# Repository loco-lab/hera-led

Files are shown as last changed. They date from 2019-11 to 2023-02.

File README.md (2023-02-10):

# hera-led
Contains all the relevant parts to create your own live HERA LED display.  
  
HERAlive.py is the main code. It shows the live status of HERA according to the dashboard.  
HERAtest.py is a playground with many different displays to use. Comment and uncomment lines under main() to change what displays.  
  
On the LoCo lab board, HERAlive is setup to run via systemd so that it automatically begins at startup.  
If it is not running, use the following sequence of commands to restart it.
  
sudo systemctl stop HERAlive  
sudo systemctl daemon-reload  
sudo systemctl start HERAlive

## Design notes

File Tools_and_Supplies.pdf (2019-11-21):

Tools and Supplies
While not listed in the bill of materials, these items are necessary for putting the display together. You may have many of them on hand already. The only thing I didn’t have in the lab already was the laser cutter, where I went to a local hobbyist group.
- Hot glue gun with plenty of glue
The LEDs and dishes are glued into place on the middle layer. Hot glue worked great for me, but you’re welcome to try other kinds of glue as well.
- Philips screwdriver
All screws I used are Philips head. Also useful for the LED power supply ports!
- Vice-grip
Good for tightening the screws. My middle board bent which made stacking the 3 boards together difficult without this.
- Scissors
For cutting the labels after printing.
- X-acto knife
Had its many uses, such as removing bad glue applications and cutting the foamcore.
- GPIO female to male jumper cables
You’ll need signal and ground cables running from the Pi to the LEDs. These specific jumper cables slip on to the GPIO pins smoothly and then insert into the LEDs plug.
- Wire cutters and strippers
You’ll need to make some custom wires that are long enough to power the LEDs towards the top of the display. I’ll describe this more in the build guide.
- Double-sided tape
For sticking the labels on the foamcore and the foamcore on the acrylic.
- Electrical tape
I had 2 jumper cables connected end to end for both signal and ground. I used electrical tape to reinforce the joint between them.
- Duct tape
You’ll have 30 extra LEDs hanging out at the end of your string, unused. I taped these to the back side of the display so that they weren’t piled up on the ground.
- Soldering station, solder, heatshrink
Again, you’ll need to make some custom wires.
- 3D printer
All the dishes are 3D printed. We used a Makerbot Replicator+.
- Laser cutter
The 3 main boards are all laser cut for precision. You need a very large laser cutter, at least 30” by 35” (the size of the hex). I used a 31” by 48”.

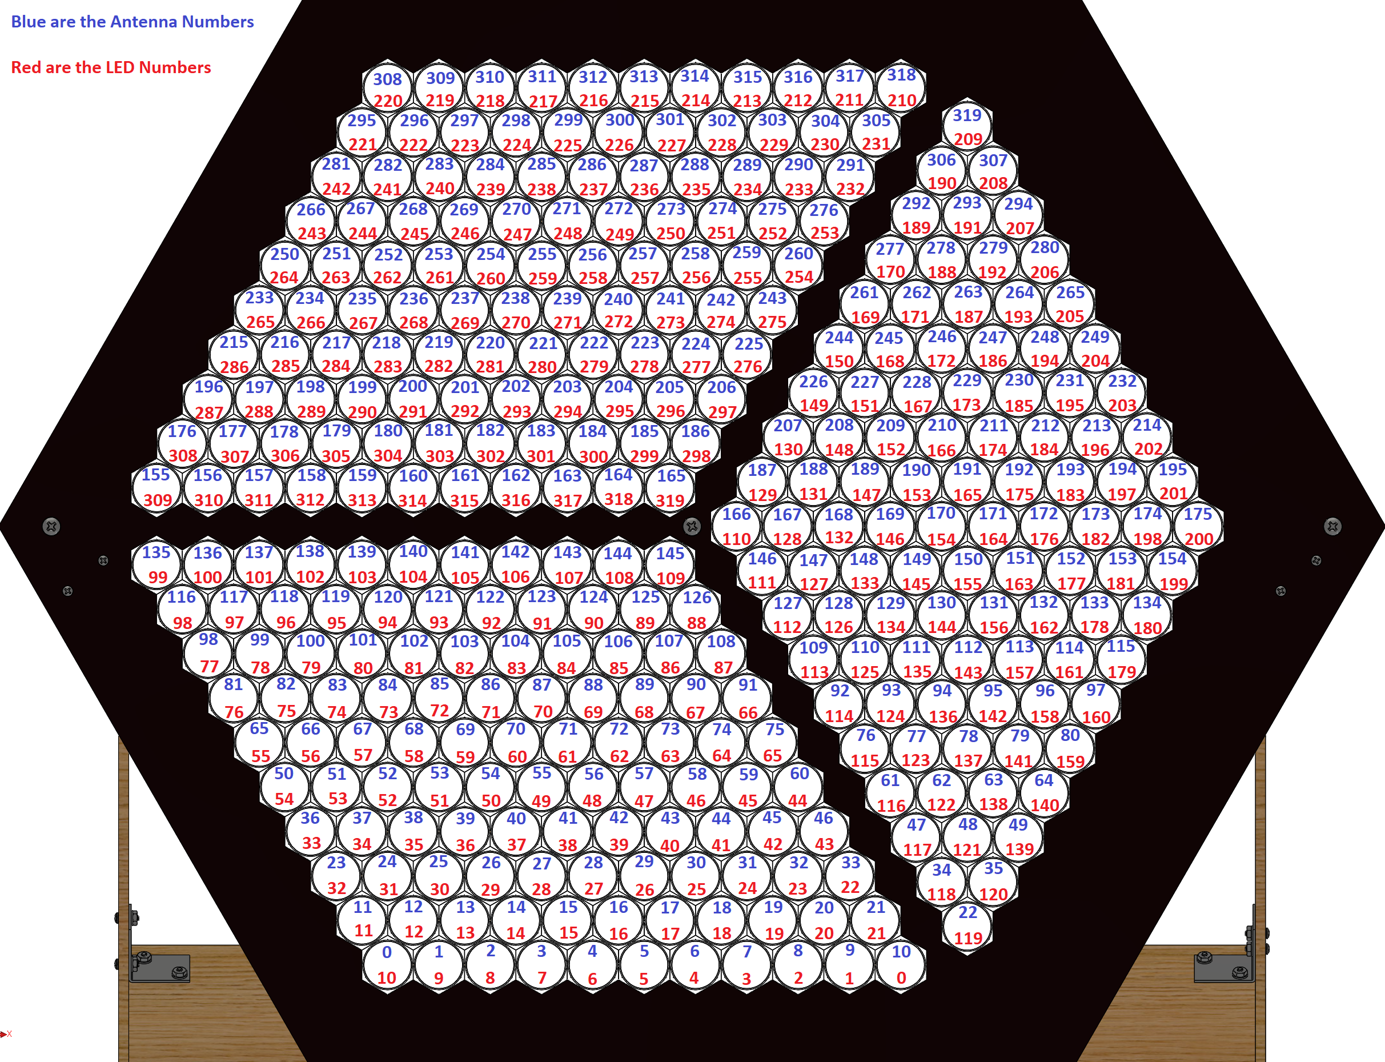
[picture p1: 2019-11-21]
Numbering_Scheme.png

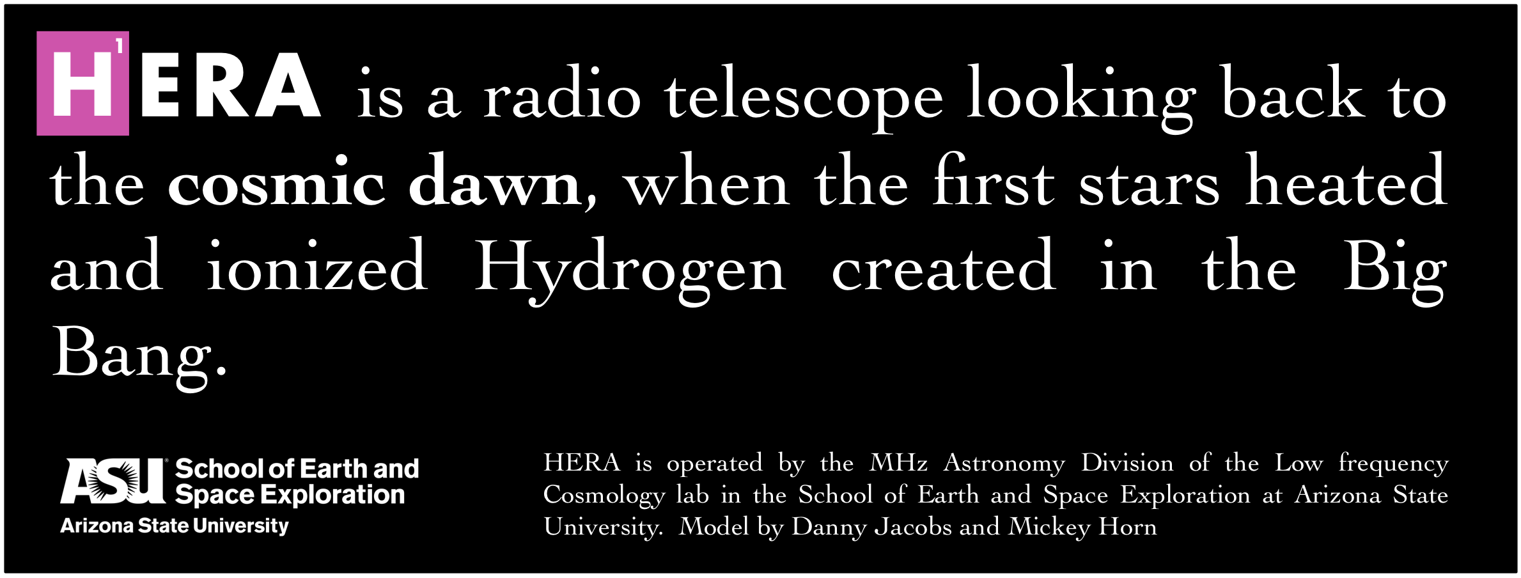
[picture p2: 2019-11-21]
Labels/Label_1.png

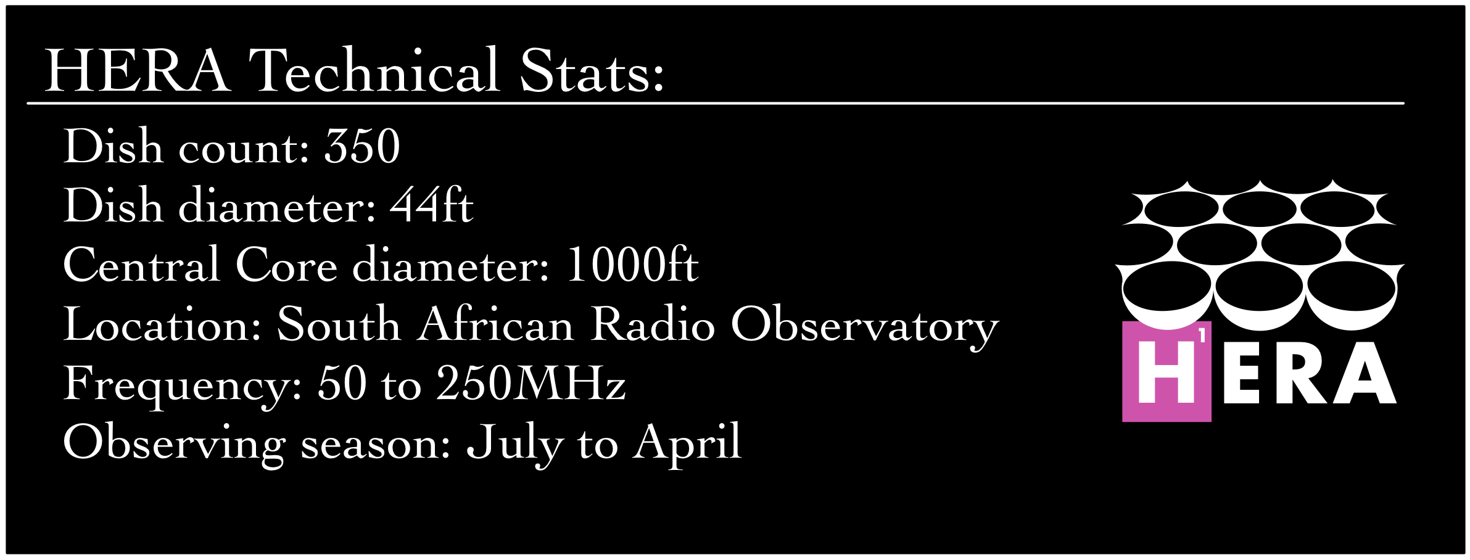
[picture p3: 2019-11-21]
Labels/Label_3.png

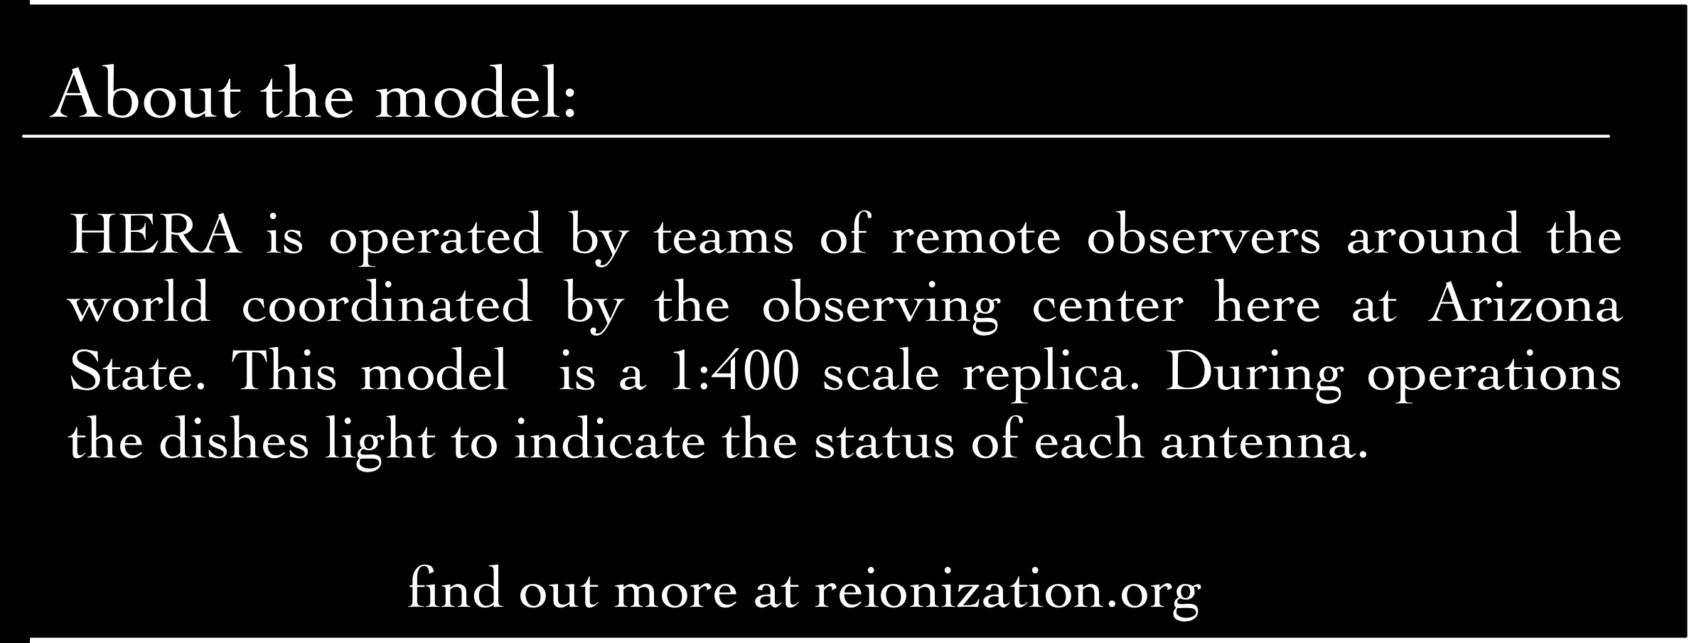
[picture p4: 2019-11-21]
Labels/Label_2.png

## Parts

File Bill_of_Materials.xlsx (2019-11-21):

Item | Specs | Quantity Needed | Quantity per Pack | Packs Needed | Price per Pack | Total Price | Link
Addressable LED Strings | --- | 320 | 500 | 1 | $118.00 | $118.00 | https://www.amazon.com/ALITOVE-LED-Individually-Addressable-Waterproof/dp/B01NCAG8KV
LED Power Supply | --- | 1 | 1 | 1 | $23.99 | $23.99 | https://www.amazon.com/dp/B06XK3X3PW/ref=cm_sw_r_cp_ep_dp_v01ZzbYYBK4NR
LED Power Supply Cable | --- | 1 | 1 | 1 | $7.99 | $7.99 | https://www.amazon.com/dp/B07CWS4BGC
Opaque Black Acrylic | 31" x 31" x 3/16" | 1 | 1 | 1 | $136.35 | $136.35 | https://www.tapplastics.com/product/plastics/cut_to_size_plastic/acrylic_sheets_color/341
Bending Plywood Board | 48" x 48" x 1/8" | 1 | 1 | 1 | $31.99 | $31.99 | https://www.homedepot.com/p/Columbia-Forest-Products-1-8-in-x-4-ft-x-4-ft-PureBond-Radius-Bending-Plywood-Project-Panel-4162/310331847
Red Oak Plywood Board | 48" x 48" x 1/4" | 1 | 1 | 1 | $41.54 | $41.54 | https://www.homedepot.com/p/Columbia-Forest-Products-1-4-in-x-4-ft-x-4-ft-PureBond-Red-Oak-Plywood-Project-Panel-Free-Custom-Cut-Available-2564/204637001
Steel Corner Bracket | 1.5" x 1.5" x 1.25" | 4 | 1 | 4 | $1.64 | $6.56 | https://www.mcmaster.com/17715a75
Titanium Pan Head Screw | M6 x 20mm | 7 | 5 | 2 | $8.75 | $17.50 | https://www.mcmaster.com/90234a367
Titanium Pan Head Screw | 6-32 x 0.5" | 12 | 1 | 12 | $5.20 | $62.40 | https://www.mcmaster.com/90234a210
Titanium Pan Head Screw | 6-32 x 0.75" | 4 | 1 | 4 | $5.93 | $23.72 | https://www.mcmaster.com/90234A215
Black Stainless Steel Washer | M6 | 7 | 100 | 1 | $9.15 | $9.15 | https://www.mcmaster.com/98269a450
Black Stainless Steel Washer | No. 6 | 16 | 100 | 1 | $3.88 | $3.88 | https://www.mcmaster.com/96765a115
Titanium Hex Nut | M6 | 7 | 1 | 7 | $4.58 | $32.06 | https://www.mcmaster.com/91927a115
Titanium Hex Nut | 6-32 | 16 | 1 | 16 | $4.48 | $71.68 | https://www.mcmaster.com/90545a007
Raspberry Pi Model 3 B+ | --- | 1 | 1 | 1 | $35.00 | $35.00 | https://www.canakit.com/raspberry-pi-3-model-b-plus.html
Raspberry Pi Case | --- | 1 | 1 | 1 | $7.95 | $7.95 | https://www.pishop.us/product/designspark-raspberry-pi-3-enclosure-black/
Pi Power Supply | --- | 1 | 1 | 1 | $8.95 | $8.95 | https://www.pishop.us/product/wall-adapter-power-supply-micro-usb-2-4a-5-25v/
Wireless Keyboard+Mouse | --- | 1 | 1 | 1 | $19.95 | $19.95 | https://www.pishop.us/product/full-size-wireless-keyboard-with-trackpad/
HDMI Cable | --- | 1 | 1 | 1 | $2.45 | $2.45 | https://www.pishop.us/product/hdmi-cable-flat-1m/
Wifi Adapter | --- | 1 | 1 | 1 | $8.95 | $8.95 | https://www.pishop.us/product/wireless-n-300mbps-usb-wifi-adapter-hx9500/
MicroSD Card | --- | 1 | 1 | 1 | $14.95 | $14.95 | https://www.pishop.us/product/microsd-card-32-gb-class-10-blank/
Clear Filament | 1.75mm | 3 | 1 | 3 | $42.00 | $126.00 | https://www.matterhackers.com/store/l/clear-translucent-pro-series-pla-filament-1.75mm/sk/MESZ27MX
Black Foamcore Board | --- | 1 | 1 | 1 | $10.00 | $10.00 | https://www.michaels.com/elmers-black-foam-boards-11x14/10308905.html
 |  |  |  |  | Final Price | $821.01

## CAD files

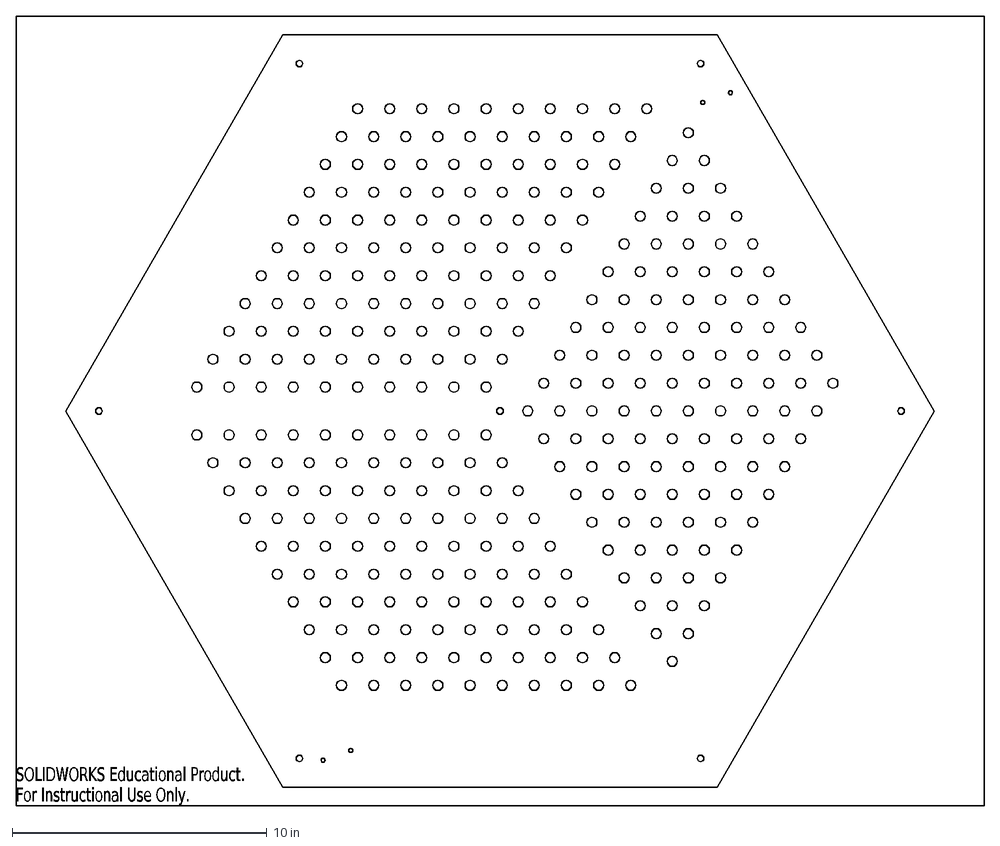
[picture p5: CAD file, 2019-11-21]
Laser_Drawings/Full_Middle_Layer_Drawing.DXF
SOLIDWORKS Educational Product.
For Instructional Use Only.

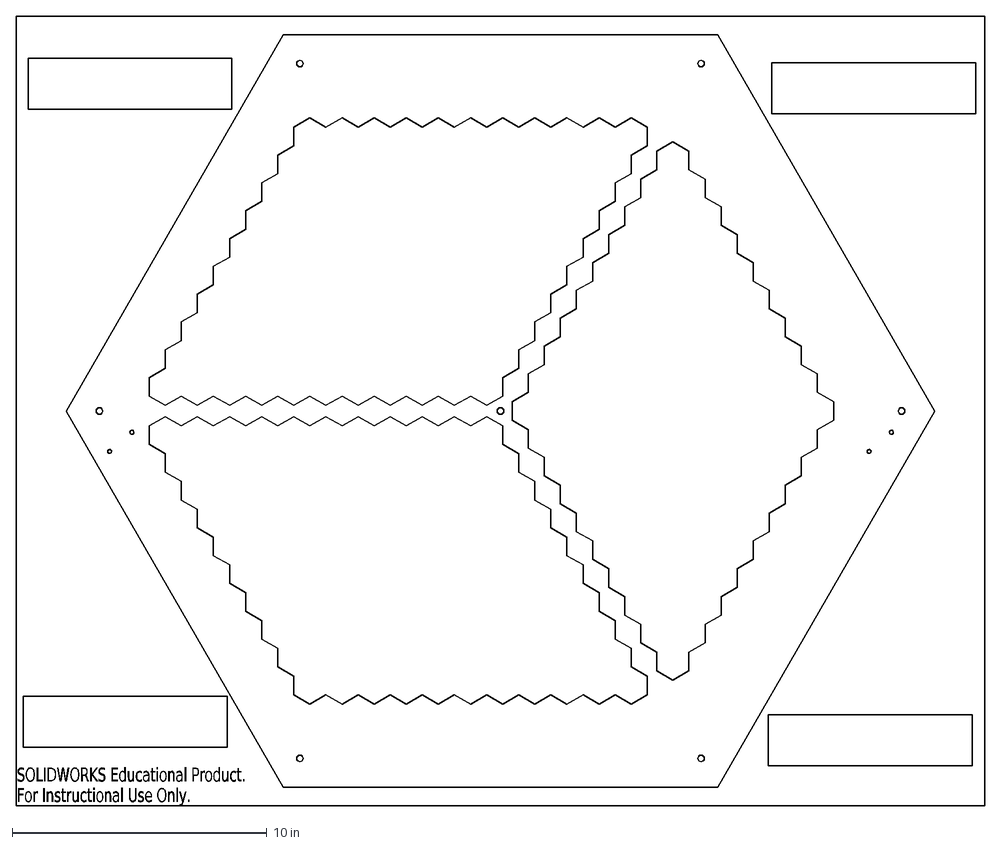
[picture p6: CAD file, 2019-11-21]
Laser_Drawings/Full_Top_Layer_Drawing.DXF
SOLIDWORKS Educational Product.
For Instructional Use Only.

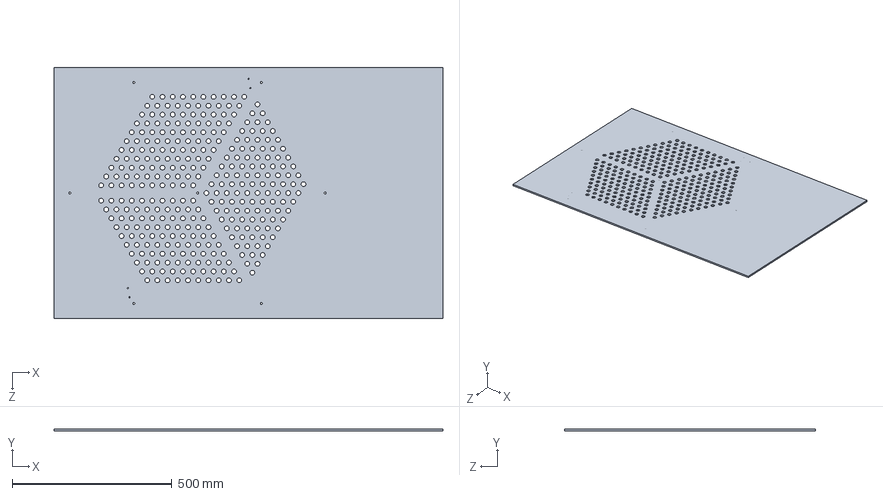
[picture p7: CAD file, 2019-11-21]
Solidworks_Assembly/Full Bottom Layer.SLDPRT
1219.2 x 6.35 x 787.4 mm

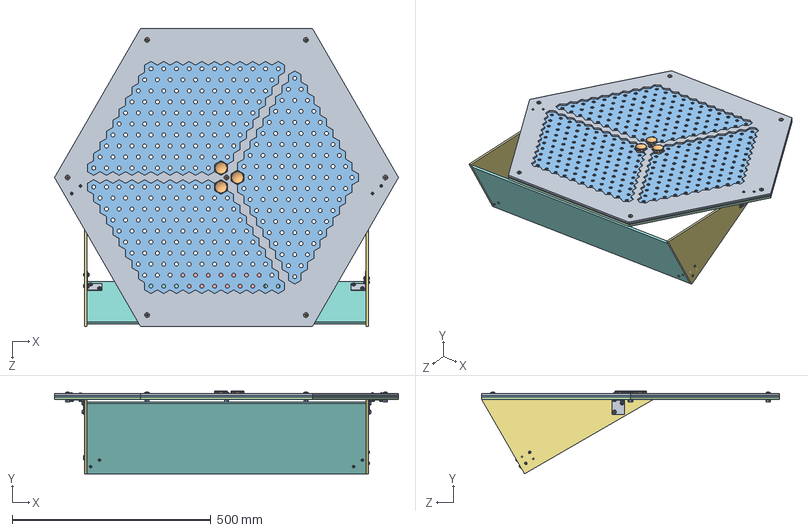
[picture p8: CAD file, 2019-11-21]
Solidworks_Assembly/HERA LED Model Assembly.SLDASM
866.0 x 208.1 x 750.0 mm
Top Layer
Scaled HERA dish LED x 3
Middle Layer
Bottom Layer
Power Supply
Pi 2011.12
Triangle Support x 2
Bottom Plank
Angle Bracket x 4
M6 x 20mm Screw x 7
M6 Nut x 7
M6 Washer x 7
6-32 x 0.75in Screw x 4
6-32 Nut x 16
6-32 Washer x 16
6-32 x 0.5in Screw x 12

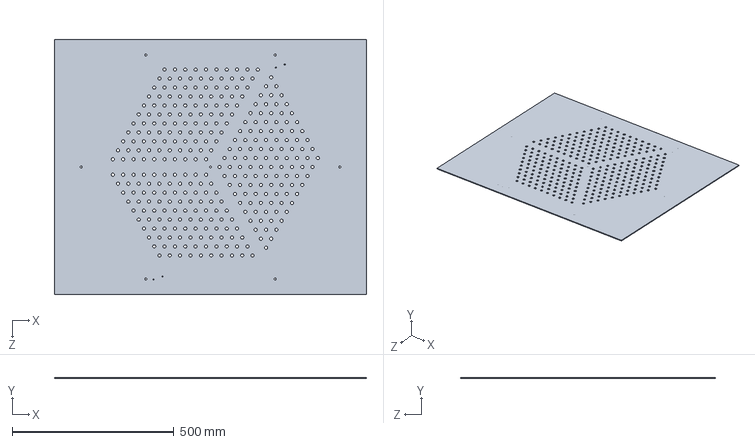
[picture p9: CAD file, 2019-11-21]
Solidworks_Assembly/Full Middle Layer.SLDPRT
965.2 x 3.17 x 787.4 mm

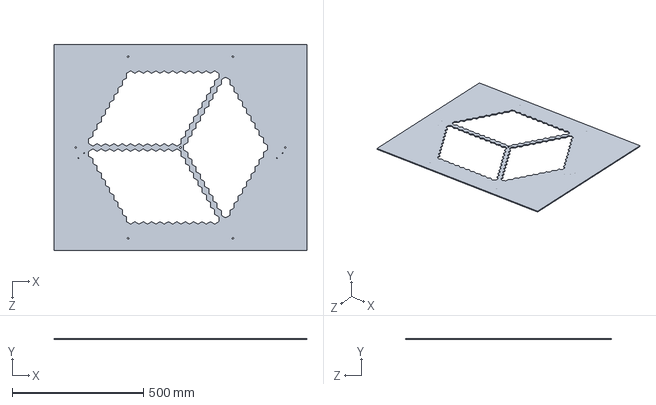
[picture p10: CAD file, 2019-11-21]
Solidworks_Assembly/Full Top Layer.SLDPRT
965.2 x 4.76 x 787.4 mm

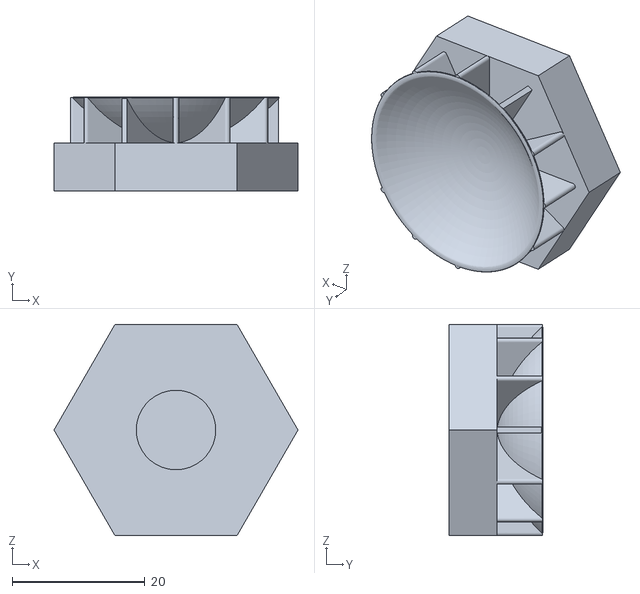
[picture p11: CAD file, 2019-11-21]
Scaled_HERA_Dish_LED_forprint.STL
36.8 x 14.2 x 31.9

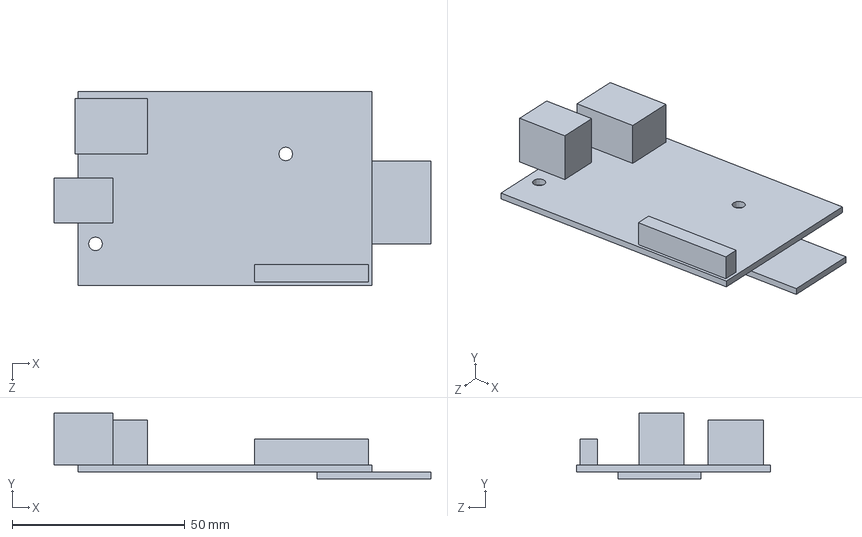
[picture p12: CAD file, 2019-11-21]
Solidworks_Assembly/Pi 2011.12.SLDPRT
109.0 x 19.0 x 56.0 mm

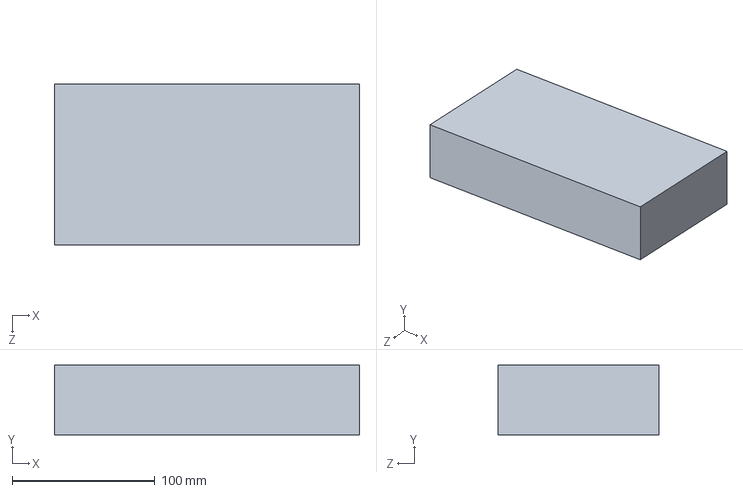
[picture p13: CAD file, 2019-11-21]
Solidworks_Assembly/Power Supply.SLDPRT
214.0 x 49.0 x 113.0 mm

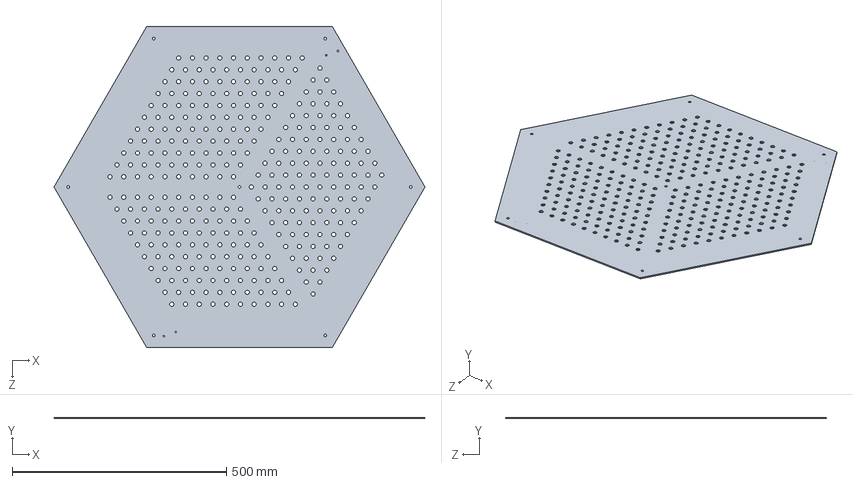
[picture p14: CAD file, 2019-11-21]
Solidworks_Assembly/Middle Layer.SLDPRT
866.0 x 3.17 x 750.0 mm

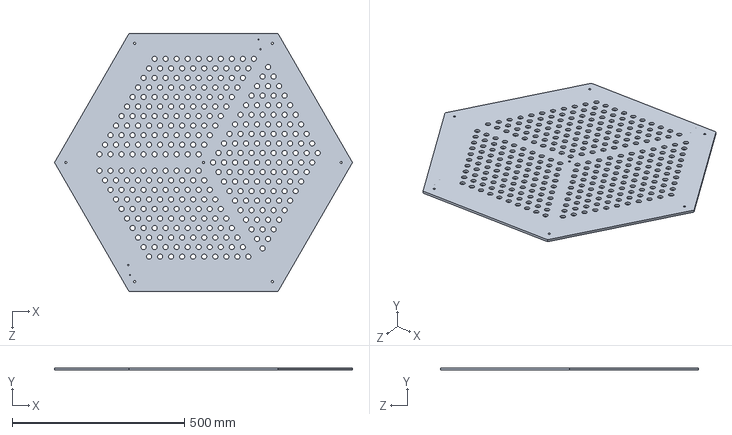
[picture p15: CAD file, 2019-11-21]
Solidworks_Assembly/Bottom Layer.SLDPRT
866.0 x 6.35 x 750.0 mm

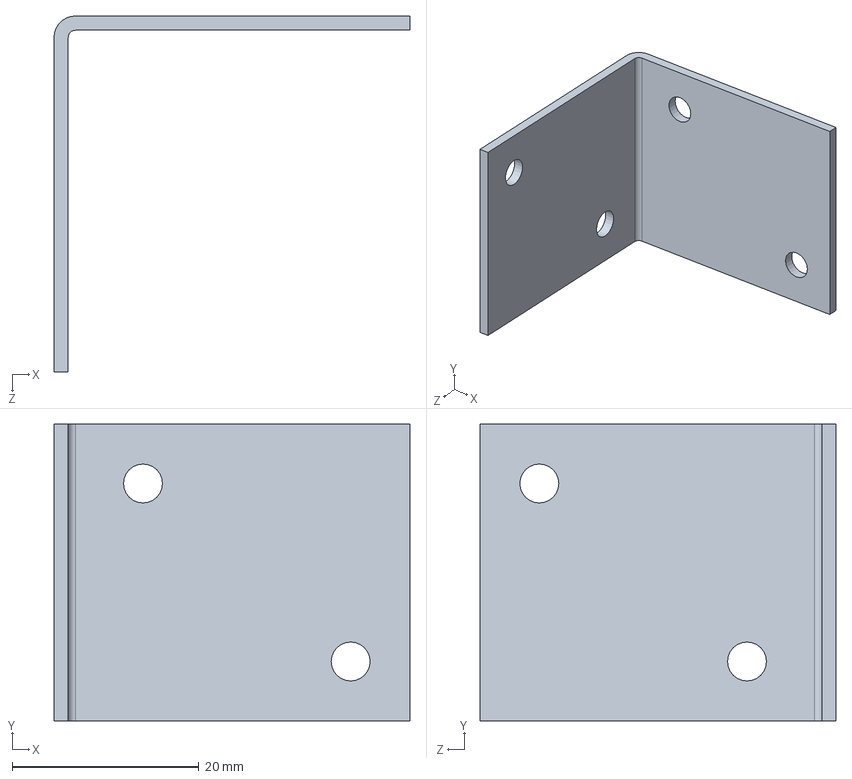
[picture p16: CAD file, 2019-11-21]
Solidworks_Assembly/Angle Bracket.SLDPRT
38.1 x 31.8 x 38.1 mm

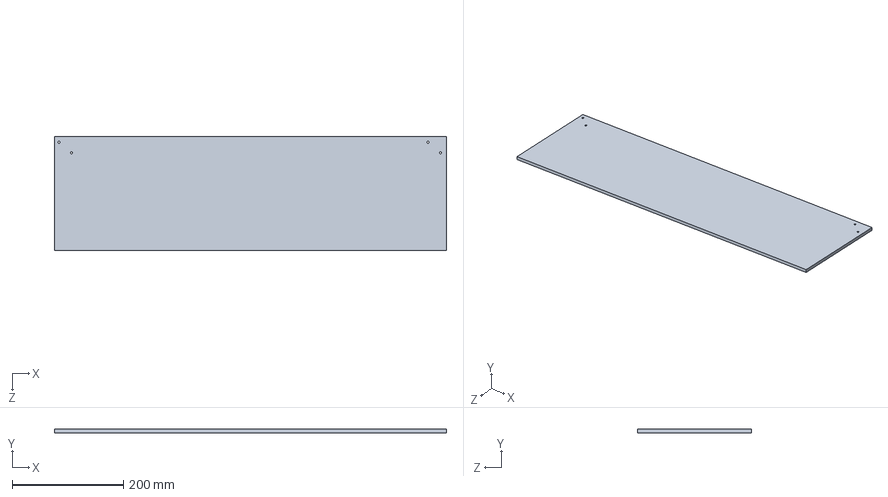
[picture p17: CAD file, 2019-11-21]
Solidworks_Assembly/Bottom Plank.SLDPRT
703.3 x 6.35 x 205.0 mm

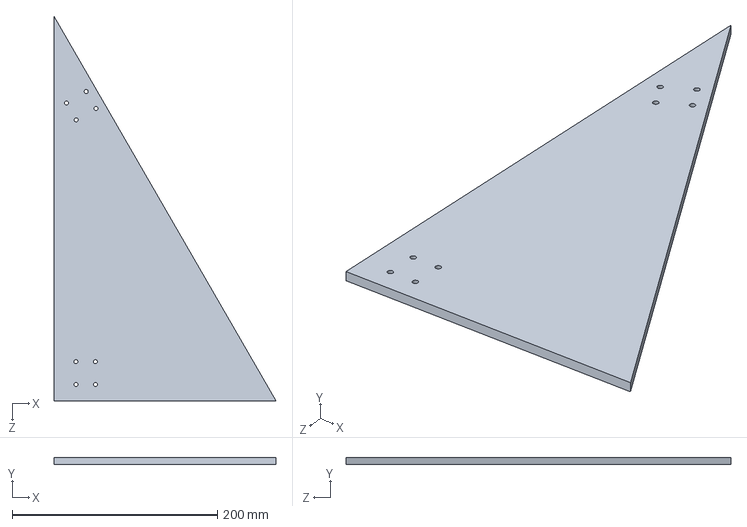
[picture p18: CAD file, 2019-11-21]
Solidworks_Assembly/Triangle Support.SLDPRT
216.5 x 6.35 x 375.0 mm

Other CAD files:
Laser_Drawings/Full_Bottom_Layer_Drawing.DXF
Solidworks_Assembly/Top Layer.SLDPRT
Solidworks_Assembly/Scaled HERA dish LED.SLDPRT
Solidworks_Assembly/6-32 x 0.75in Screw Assy.SLDASM
Solidworks_Assembly/6-32 Nut.SLDPRT
Solidworks_Assembly/6-32 Washer.SLDPRT
Solidworks_Assembly/6-32 x 0.5in Screw Assy.SLDASM
Solidworks_Assembly/6-32 x 0.5in Screw.SLDPRT
Solidworks_Assembly/6-32 x 0.75in Screw.SLDPRT
Solidworks_Assembly/Full Bottom Layer.DXF
Solidworks_Assembly/Full Bottom Layer.SLDDRW
Solidworks_Assembly/Full Middle Layer.SLDDRW
Solidworks_Assembly/Full Top Layer.SLDDRW
Solidworks_Assembly/M6 Nut.SLDPRT
Solidworks_Assembly/M6 Screw Assy.SLDASM
Solidworks_Assembly/M6 Washer.SLDPRT
Solidworks_Assembly/M6 x 20mm Screw.SLDPRT

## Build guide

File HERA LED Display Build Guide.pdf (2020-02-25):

HERA LED Display Build Guide
This document will walk you through how I built the HERA LED display so that you can do it yourself. Some things in this guide may be slightly different to my process, with the intention of making the build quicker and smoother. I would HIGHLY recommend reading the “Problems and Suggested Improvements” document before starting this guide, as it will save you headache in the long run.
Step 1: Print the Dishes
You have 320 individual clear plastic dishes to print, so I would recommend starting this before anything else. It’s very simple to start a print and then start working on other things while it goes. My printer took about 4 hours to print 10 dishes at a time. This means I could expect AT LEAST 128 hours of printing time, ignoring failed prints and mechanical issues. I could only churn out 20-30 dishes a day, so get this started early. Printing time will vary based on your printer and availability. Make sure you are printing the Scaled_HERA_Dish_LED_forprint.STL file.
Step 2: Laser Cut the Boards
Next step is to laser cut the acrylic and two plywood boards. Make sure that you match the drawings to the correct board: top=acrylic, middle=thin plywood, bottom=thick plywood. The bottom board also has cuts for the triangle supports and bottom brace to keep the display standing. Use the Full_XXX_Layer_Drawing.DXF files located under Laser_Drawings with your laser cutter software.
Step 3: Assemble the Boards
Stack the boards on top of each other and check that they are oriented correctly by checking that you can see through each hole from the back side. Place 7 M6 x 20mm screws through the middle hole and the 6 holes by the corners, with a washer on each side and a nut to hold it in place (every screw in this model uses 2 washers and a nut). Tighten each screw evenly to ensure flatness. Then, place 4 6-32 x 0.75” screws through the smaller, unused holes on the front. Affix a corner bracket to the backside of the display with the screws, with the open side of the bracket towards the inside of the display.
Step 4: Assemble the Supports
Attach the bottom support board to the triangle supports with 8 6-32 x 0.5” screws and angle brackets. Then attach the triangle supports to the angle brackets on the back of the main model boards, with the 4 more 6-32 x 0.5” screws. Your display should now be able to stand up, but be careful as it is top-heavy.

Step 5: Glue the LEDs
This step is very tedious and time consuming, as you must individually glue each LED into its hole on the backside of the display. Additionally, it is vital that you FOLLOW THE CORRECT ORDER! The code relies on the light indices, which are determined by the order in which they are wired up, so make sure you follow the map. You will start in the bottom right corner of the bottom third, and zipper your way up to the top right corner. From there, go to the left corner of the vertical third, and zipper again, starting towards the bottom right and ending in the top corner. Then jump over to the top right corner of the top third, and zipper down to the bottom right corner. I applied a healthy amount of glue to the part of the LED where the hard bulb casing meets the soft plastic sheath, and then just stuck it into place, and held it until the glue hardened (~1 minute). You’ll notice that the wires between the LEDs are stiff and sometimes twisted; do your best to straighten them out before gluing. Most are wired in such a way where the wires will form nice arches, but not always. You’ll have to add a new strand every 50 LEDs, just make sure you plug it in before gluing so that you are in the correct order.
Step 6: Add the Labels
If you are planning to use foamcore and printed labels, this step is very simple. Print out the 3 label images on a regular piece of paper. Make the images go almost to the edge of the paper, this should result in a good size. Cut the labels out of the paper with some scissors and place them on a section of foamcore. Cut out the foamcore to be slightly larger than the printed label. Tape the label to the foamcore and the foamcore to the acrylic with double-sided tape.
Step 7: Hooking up Power
You will want to add power to the beginning, middle, and end of your LED string, or the lights at the end of the string will be very faint. Each 50 LED strand of lights has two lights with extra power and ground input wires. I trimmed off all of these except for the ones I was planning on sending power to and soldered them to the 3 pairs of wires from the LEDs I wanted to give power. You will want to check and play with the lengths of each wire so that they all reach your power supply that is hanging out on the support board. In the end, you should have 3 power and 3 ground wires going from the power supply to different parts in your strand. The power supply simply plugs into a wall outlet with the accompanying cable.
Step 8: Hooking up the Pi
The Pi setup is very straight forward; plug in its power supply, HDMI to a monitor, and a mouse and keyboard to be able to power and use it. Then, use some jumper cables to wire the GPIO header to the start of the LED strand. You’ll need a ground wire going from pin 6 into the ground port (blue wire on LEDs). You’ll also need a signal wire going from pin 12 into the signal port (white wire on LEDs).

Step 9: Setting up the Software
Feel free to install whatever OS you’d like on your Pi. I will note that I elected to use Ubuntu Mate because ASU Wi-Fi does not take kindly to Pi’s and Raspbian. When setting up the wifi, you may need to add your network as a hidden network. Then, go to this page: https://tutorials-raspberrypi.com/connect-control-raspberry-pi-ws2812-rgb-led-strips/ (https://tutorials-raspberrypi.com/connect-control-raspberry-pi-ws2812-rgb-led-strips/) . Scroll down to the “Preparation and Installation” section, and in your terminal, run the commands that are listed, eventually resulting in installing the rpi_ws281x library.
Step 10: Running the Display
Once you’ve gotten this far, all you should have to do is make sure you have HERAtest.py on the Pi somewhere. Navigate to that folder, and run
sudo python HERAtest.py -c
Your lights should now display the live HERA status! If you wish to change it up, HERAtest.py has some other display modes you can try. Scroll down to the bottom of the script, and underneath the main loop, you can comment and uncomment some functions to change what is displayed!

And you’re now operational! Enjoy your display!

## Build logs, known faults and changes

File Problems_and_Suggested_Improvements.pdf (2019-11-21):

Problems and Suggested Improvements
As this was my first time making this, there were some problems and things that could have been done better. This will list out those problems and my suggested solutions.
- Plywood boards warp and don’t stay flat, no matter how much you try.
- This is a problem for two reasons. First is that any warps in the board while laser cutting will lead to cuts being slightly out of place. Second, assembling the 3 boards together is much more difficult. Despite my best efforts to keep the boards flat by clamping them together, placing them under heavy objects, and getting them damp before cutting, they would never stay flat.
- I’d recommend trying to find some MDF of the same thickness. This was suggested to me by guys at the hobbyist center where I was doing my laser cutting.
- Etched text needs to be thicker.
- Our original plan was to etch the labels on and paint them white. Unfortunately, the text was so small that when peeling off the paper cover, much of the paint came with it. I attempted to fix this by painting with a thumbtack, but it was not a pretty sight.
- This is why we ended up with the black foamcore and printed labels. If you want to try etching and painting, go for it, but make the text thicker and bigger.
- Titanium nuts and bolts are overkill.
- I selfishly purchased titanium nuts and bolts thinking that they’d be darker than they are and look better on the front of the model. However, they’re not all that much darker while being a lot more expensive.
- Just standard screws would be more than enough. You can paint over them if you really don’t want them to stick out.
- The angle brackets did not fit perfectly.
- I am not sure where the error happened, but when trying to assemble the display, the angle brackets did not fit to the laser cut holes on the supports. I had to go to the machine shop and make the holes on the brackets farther apart.
- I’ll fix the error once I find out where it originated from. Until then, you can either double check my model and adjust the bracket screw holes, or plan on machining the brackets like I did.
- We ended up not needing the Wifi adapter for the Pi.
- The Raspberry Pi Model 3 B+ has it’s own built in Wifi connectivity, so the Wifi adapter we purchased is not being used. Depending on your Pi and Network, you may or may not need it.
- Check your Pi’s Wifi capability before buying an adapter.
- The model is top heavy and can easily be pushed over.

- It’ll stand up on its own, but a little nudge at the top is enough to make it start falling backwards. I made the triangle supports from drawing a square around the hex, without thinking of this.
- You can either increase the slant of the supports, put something behind the model, or weigh down the base. We are doing a combination of the latter 2.

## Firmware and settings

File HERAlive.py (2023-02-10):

#!/usr/bin/env python3
#Author: Mickey Horn
#Live status script for HERA LED model. Ran automatically at startup via systemd.

import time
from neopixel import *
import argparse
import pandas as pd
import numpy as np
from datetime import datetime
import math
import random
#import matplotlib.pyplot as plt
#import matplotlib.colors as clr

parser = argparse.ArgumentParser()
parser.add_argument('-c', '--clear', action='store_true', help='clear the display on exit')
args = parser.parse_args()

# LED strip configuration:
LED_COUNT      = 350     # Number of LED pixels.
LED_PIN        = 18      # GPIO pin connected to the pixels (18 uses PWM!).
LED_FREQ_HZ    = 800000  # LED signal frequency in hertz (usually 800khz)
LED_DMA        = 10      # DMA channel to use for generating signal (try 10)
LED_BRIGHTNESS = 55      # Set to 0 for darkest and 255 for brightest
LED_INVERT     = False   # True to invert the signal (when using NPN transistor level shift)
LED_CHANNEL    = 0       # set to '1' for GPIOs 13, 19, 41, 45 or 53

# Correlates the antenna number defined by HERA to the LED number in the sequential string. Antenna#:LED#
scheme = {
    0:10, 1:9, 2:8, 3:7, 4:6, 5:5, 6:4, 7:3, 8:2, 9:1, 10:0,
    11:11, 12:12, 13:13, 14:14, 15:15, 16:16, 17:17, 18:18, 19:19, 20:20, 21:21,
    22:119,
    23:32, 24:31, 25:30, 26:29, 27:28, 28:27, 29:26, 30:25, 31:24, 32:23, 33:22,
    34:118, 35:120,
    36:33, 37:34, 38:35, 39:36, 40:37, 41:38, 42:39, 43:40, 44:41, 45:42, 46:43,
    47:117, 48:121, 49:139,
    50:54, 51:53, 52:52, 53:51, 54:50, 55:49, 56:48, 57:47, 58:46, 59:45, 60:44,
    61:116, 62:122, 63:138, 64:140,
    65:55, 66:56, 67:57, 68:58, 69:59, 70:60, 71:61, 72:62, 73:63, 74:64, 75:65,
    76:115, 77:123, 78:137, 79:141, 80:159,
    81:76, 82:75, 83:74, 84:73, 85:72, 86:71, 87:70, 88:69, 89:68, 90:67, 91:66,
    92:114, 93:124, 94:136, 95:142, 96:158, 97:160,
    98:77, 99:78, 100:79, 101:80, 102:81, 103:82, 104:83, 105:84, 106:85, 107:86, 108:87,
    109:113, 110:125, 111:135, 112:143, 113:157, 114:161, 115:179,
    116:98, 117:97, 118:96, 119:95, 120:94, 121:93, 122:92, 123:91, 124:90, 125:89, 126:88,
    127:112, 128:126, 129:134, 130:144, 131:156, 132:162, 133:178, 134:180,
    135:99, 136:100, 137:101, 138:102, 139:103, 140:104, 141:105, 142:106, 143:107, 144:108, 145:109,
    146:111, 147:127, 148:133, 149:145, 150:155, 151:163, 152:177, 153:181, 154:199,
    155:309, 156:310, 157:311, 158:312, 159:313, 160:314, 161:315, 162:316, 163:317, 164:318, 165:319,
    166:110, 167:128, 168:132, 169:146, 170:154, 171:164, 172:176, 173:182, 174:198, 175:200,
    176:308, 177:307, 178:306, 179:305, 180:304, 181:303, 182:302, 183:301, 184:300, 185:299, 186:298,
    187:129, 188:131, 189:147, 190:153, 191:165, 192:175, 193:183, 194:197, 195:201,
    196:287, 197:288, 198:289, 199:290, 200:291, 201:292, 202:293, 203:294, 204:295, 205:296, 206:297,
    207:130, 208:148, 209:152, 210:166, 211:174, 212:184, 213:196, 214:202,
    215:286, 216:285, 217:284, 218:283, 219:282, 220:281, 221:280, 222:279, 223:278, 224:277, 225:276,
    226:149, 227:151, 228:167, 229:173, 230:185, 231:195, 232:203,
    233:265, 234:266, 235:267, 236:268, 237:269, 238:270, 239:271, 240:272, 241:273, 242:274, 243:275,
    244:150, 245:168, 246:172, 247:186, 248:194, 249:204,
    250:264, 251:263, 252:262, 253:261, 254:260, 255:259, 256:258, 257:257, 258:256, 259:255, 260:254,
    261:169, 262:171, 263:187, 264:193, 265:205,
    266:243, 267:244, 268:245, 269:246, 270:247, 271:248, 272:249, 273:250, 274:251, 275:252, 276:253,
    277:170, 278:188, 279:192, 280:206,
    281:242, 282:241, 283:240, 284:239, 285:238, 286:237, 287:236, 288:235, 289:234, 290:233, 291:232,
    292:189, 293:191, 294:207,
    295:221, 296:222, 297:223, 298:224, 299:225, 300:226, 301:227, 302:228, 303:229, 304:230, 305:231,
    306:190, 307:208,
    308:220, 309:219, 310:218, 311:217, 312:216, 313:215, 314:214, 315:213, 316:212, 317:211, 318:210,
    319:209
}

# LED numbers of clock hands.
hourhand01 = [319,298,297,276,275,254,253,232,231] # For example, a line pointing from the center to 1 o'clock.
hourhand02 = [110,131,152,173,194]
hourhand03 = [110,128,132,146,154,164,176,182,198]
hourhand04 = [110,127,134,143,158]
hourhand05 = [110,111,112,113,114,115,116,117,118]
hourhand06 = [109,86,63,40,17]
hourhand07 = [109,89,85,69,61,49,37,29,13]
hourhand08 = [109,90,83,72,57]
hourhand09 = [109,108,107,106,105,104,103,102,101,100]
hourhand10 = [319,300,293,282,267]
hourhand11 = [319,299,295,279,271,259,247,239,223]
hourhand12 = [319,296,273,250,227]
hourhands = [hourhand01,hourhand02,hourhand03,hourhand04,hourhand05,hourhand06,hourhand07,hourhand08,hourhand09,hourhand10,hourhand11,hourhand12]

# All LEDs on the outer edge, starting from the top center and going clockwise.
sec_ring = [214,213,212,211,210,209,208,207,206,205,204,203,202,201,200,199,180,179,160,159,140,139,120,119,0,1,2,3,4,5,6,7,8,9,10,11,32,33,54,55,76,77,98,99,309,308,287,286,265,264,243,242,221,220,219,218,217,216,215]

# Correlates seconds in time with an LED on the edge. Second:LED#
secs_dict = { 
    '00':214, '01':213, '02':212, '03':211, '04':210,
    '05':209, '06':208, '07':207, '08':206, '09':205,
    '10':204, '11':203, '12':202, '13':201, '14':200,
    '15':199, '16':180, '17':179, '18':160, '19':159,
    '20':140, '21':139, '22':120, '23':119, '24':0,
    '25':1, '26':2, '27':3, '28':4, '29':5,
    '30':6, '31':7, '32':8, '33':9, '34':10,
    '35':11, '36':32, '37':33, '38':54, '39':55,
    '40':76, '41':77, '42':98, '43':99, '44':309,
    '45':308, '46':287, '47':286, '48':265, '49':264,
    '50':243, '51':242, '52':221, '53':220, '54':219,
    '55':218, '56':217, '57':216, '58':215, '59':215
}

def clear():
# Turns off all LEDs.
    for i in range(LED_COUNT): strip.setPixelColorRGB(i,0,0,0)
    strip.show()

def colorscale(mag,cmin,cmax):
# Returns a tuple of floats between 0 and 255 for RGB, scaling from green to yellow.
# Typically used where mag is the magnitude of an antenna's spectra, cmin is a lower boundary of all antenna spectra, and cmax is an upper boundary.
    try: x = float(mag-cmin)/(cmax-cmin) # x scales from 0 to 1
    except ZeroDivisionError: x=0.5 # In case cmax==cmin.
    r = int(x*255)
    g = 255
    b = int(75-(x*75))
    return r,g,b
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

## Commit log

2019-11-21 Drawings for laser cutting
    DXFs that can be directly passed into your laser cutting software for the 3 major layers of the model.
    [Full_Bottom_Layer_Drawing.DXF, Full_Middle_Layer_Drawing.DXF, Full_Top_Layer_Drawing.DXF]
2019-11-21 Labels to print and add to the front of the model
    PNGs made by Danny. Printed out and taped to the front of the model.
2019-11-21 Picture of the numbering scheme
    Contains antenna numbers and LED index numbers for each dish. Just a handy reference document.
2019-11-21 Bill of materials spreadsheet
    Spreadsheet containing all the materials used to construct the display, and links to purchase them. Does not include tools and supplies such as hot glue.
    [Bill_of_Materials.xlsx]
2019-11-21 Solidworks files
    Solidworks parts, assemblies, and drawings for the display.
    [6-32 Nut.SLDPRT, 6-32 Washer.SLDPRT, 6-32 x 0.5in Screw Assy.SLDASM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]
2019-11-21 Python script that controls the LEDs
    This script controls the LEDs. Currently it updates the live antenna status every 2 minutes. There are many other functions included that can be ran instead by changing commented lines in the main lo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
2019-11-21 Putting things in folders
    Putting files in folders to keep organized
    [6-32 Nut.SLDPRT, 6-32 Washer.SLDPRT, 6-32 x 0.5in Screw Assy.SLDASM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]
2019-11-21 fixing BoM
    had some incorrect values due to copy/paste not translating functions
    [Bill_of_Materials.xlsx]
2019-11-21 Added LEDs
    Somehow forgot about the most important part!
    [Bill_of_Materials.xlsx]
2019-11-21 Added LED PSU
    Forgot LED power supply and accompanying cable
    [Bill_of_Materials.xlsx]
2020-02-25 removed print statement
2020-02-27 longer LED strand so back ones turn off
